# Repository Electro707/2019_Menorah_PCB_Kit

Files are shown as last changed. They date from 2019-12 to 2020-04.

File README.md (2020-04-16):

# 2019_Menorah_PCB_Kit
A soldering kit in the shape of menorah powered by an ATtiny84

This repository is archived, as it's a one-time design.
Now files are hosted on Google Drive.

Link to website, in which the Google Drive link can be found:
[Link](https://electro707.com/documentation/PCB/2019_Menorah/index.php)

I may create a new general reposity for the kit that will be updated as time goes on 
(there also won't be any of the University of New Haven logos on that one).

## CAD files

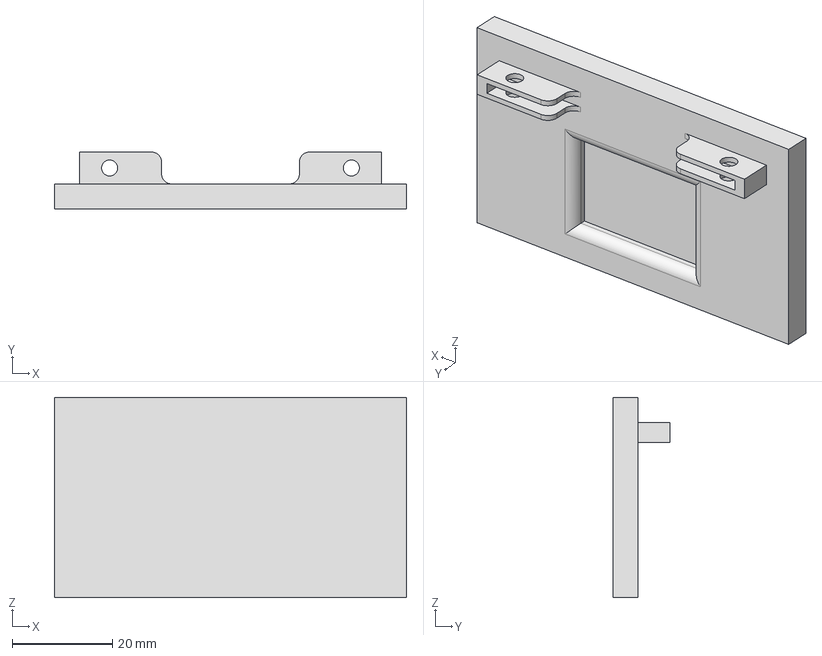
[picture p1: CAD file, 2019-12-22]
Base STEP and STL/Base.stp
70.3 x 11.3 x 40.0 mm

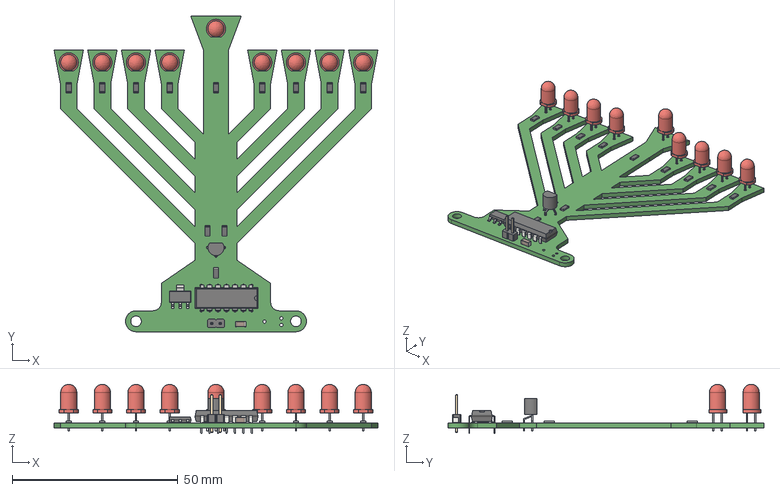
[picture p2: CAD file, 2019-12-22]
CAD-Inventor/Hanukkah.step
97.8 x 95.2 x 14.9 mm

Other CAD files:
CAD-Inventor/Drawing.dwg
Base STEP and STL/Base.stl
CAD-Inventor/9V Battery.ipt
CAD-Inventor/Assembly - Whole.iam
CAD-Inventor/Exploded Views.ipn
CAD-Inventor/Holder.ipt

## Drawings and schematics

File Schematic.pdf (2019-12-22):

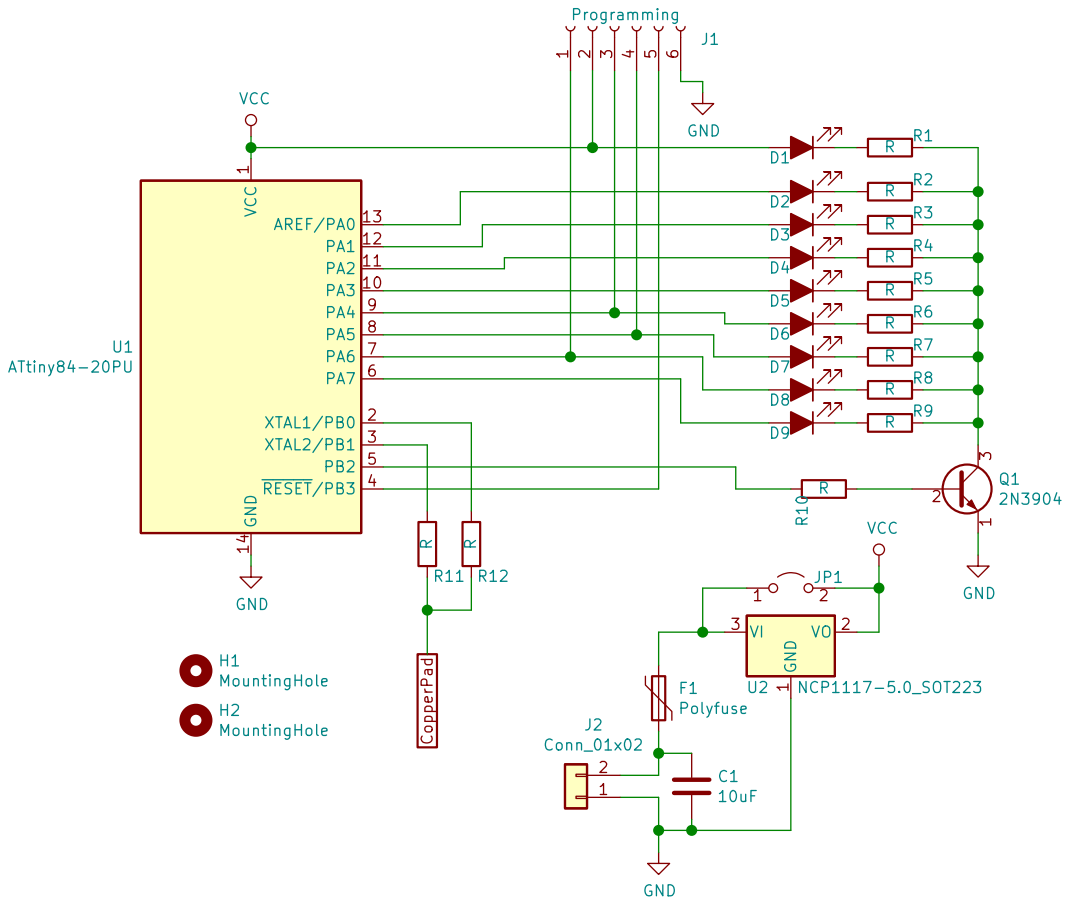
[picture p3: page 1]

1 PA3 10 PA2 11 PA1 12 AREF/PA0 13 GND 14 XTAL1/PB0 2 XTAL2/PB1 3 RESET/PB3 4 PB2 5 PA7 6 PA6 7 PA5 8 PA4 9 U1 ATtiny84-20PU CopperPad R12 R

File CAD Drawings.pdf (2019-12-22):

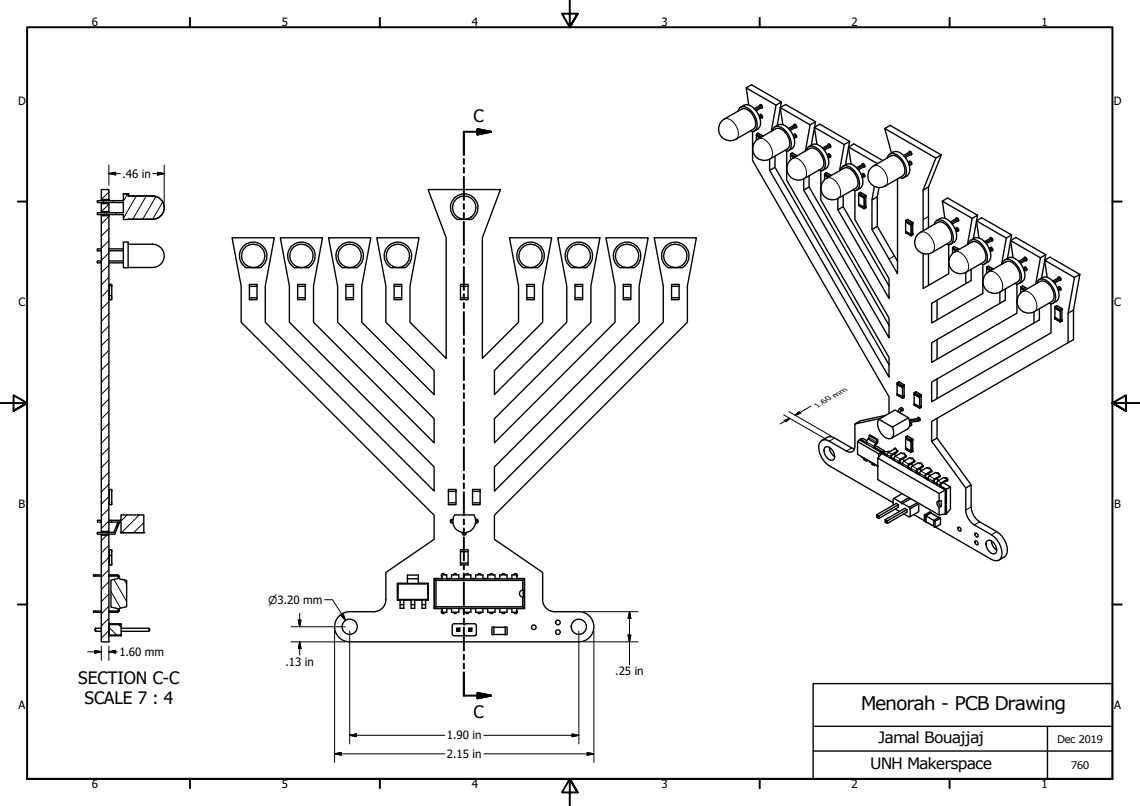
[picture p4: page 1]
SECTION C-C SCALE 7 : 4

Menorah - PCB Drawing

Jamal Bouajjaj | Dec 2019
UNH Makerspace | 760

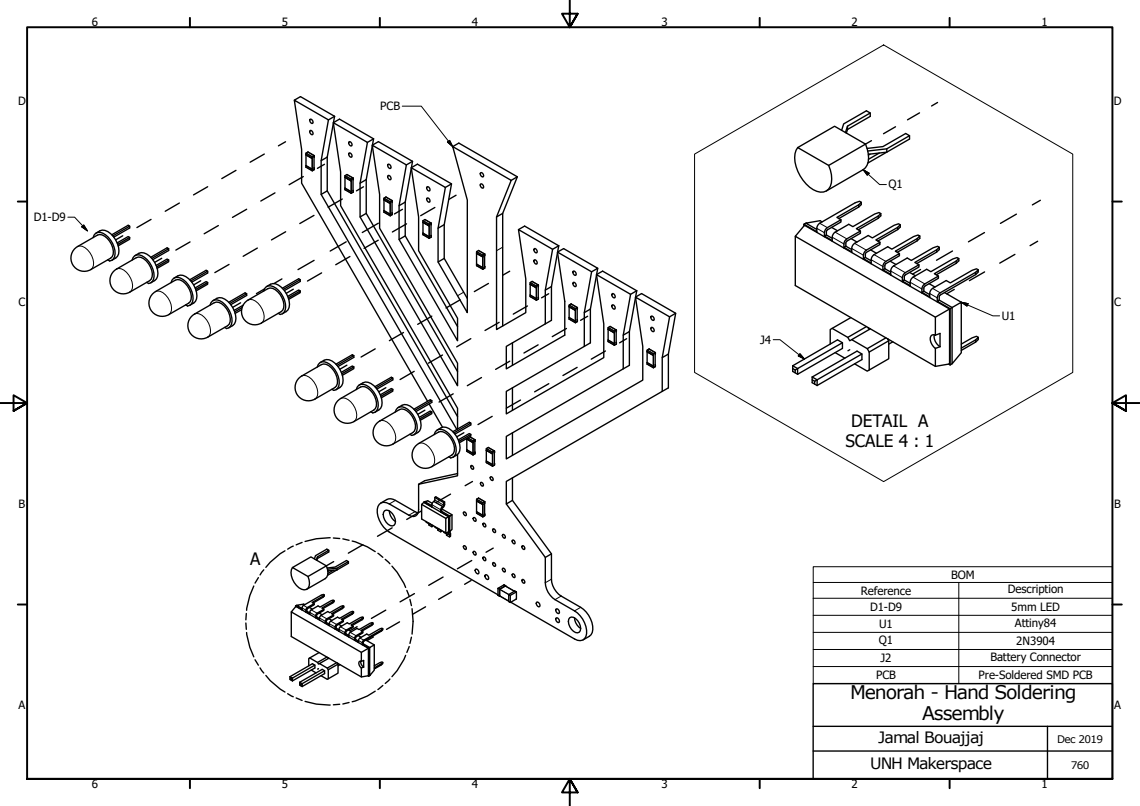
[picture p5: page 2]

R e fe r e n c e | D e s c r i p t i o n
D 1 -D 9 | 5 m m L E D
U 1 | At t i n y 8 4
Q 1 | 2 N 3 9 0 4
J 2 | B a t t e r y C o n n e c t o r
P C B | P r e -S old e r e d S M D P C B

J a m al B o u aj j aj | D e c
U N H M a k e r s p a c e

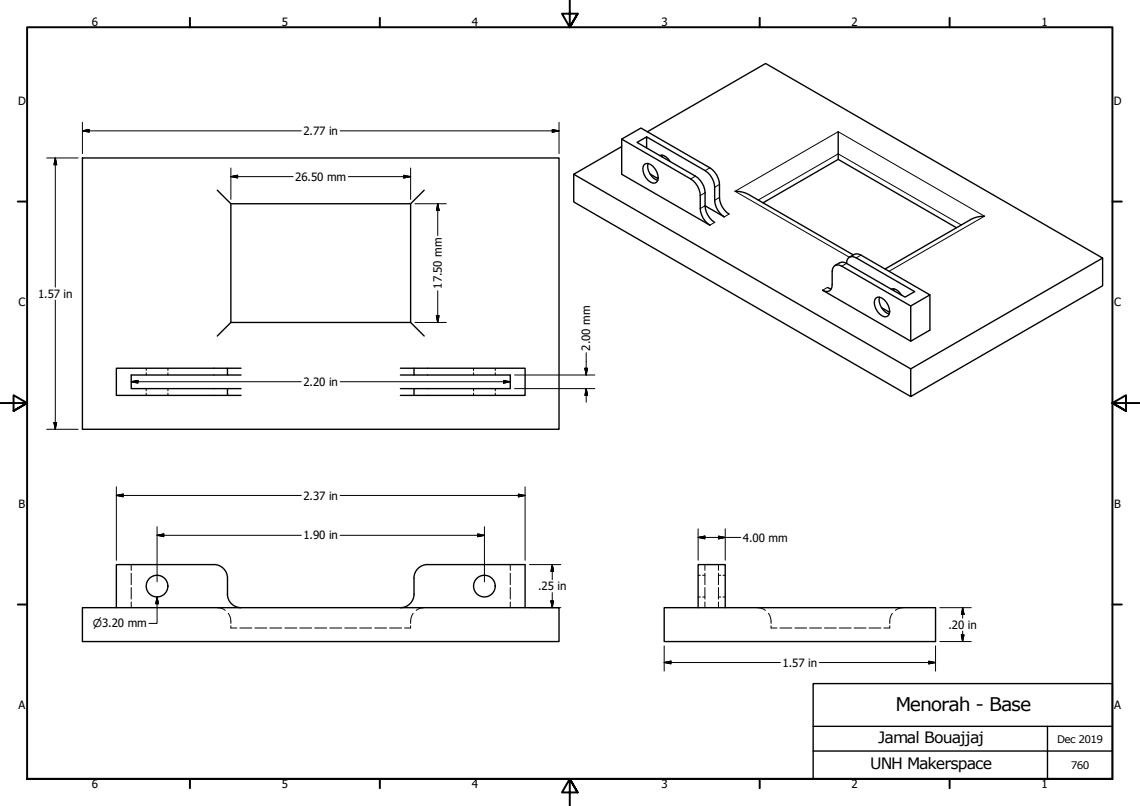
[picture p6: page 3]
Menorah - Base; Jamal Bouajjaj; Dec 2019

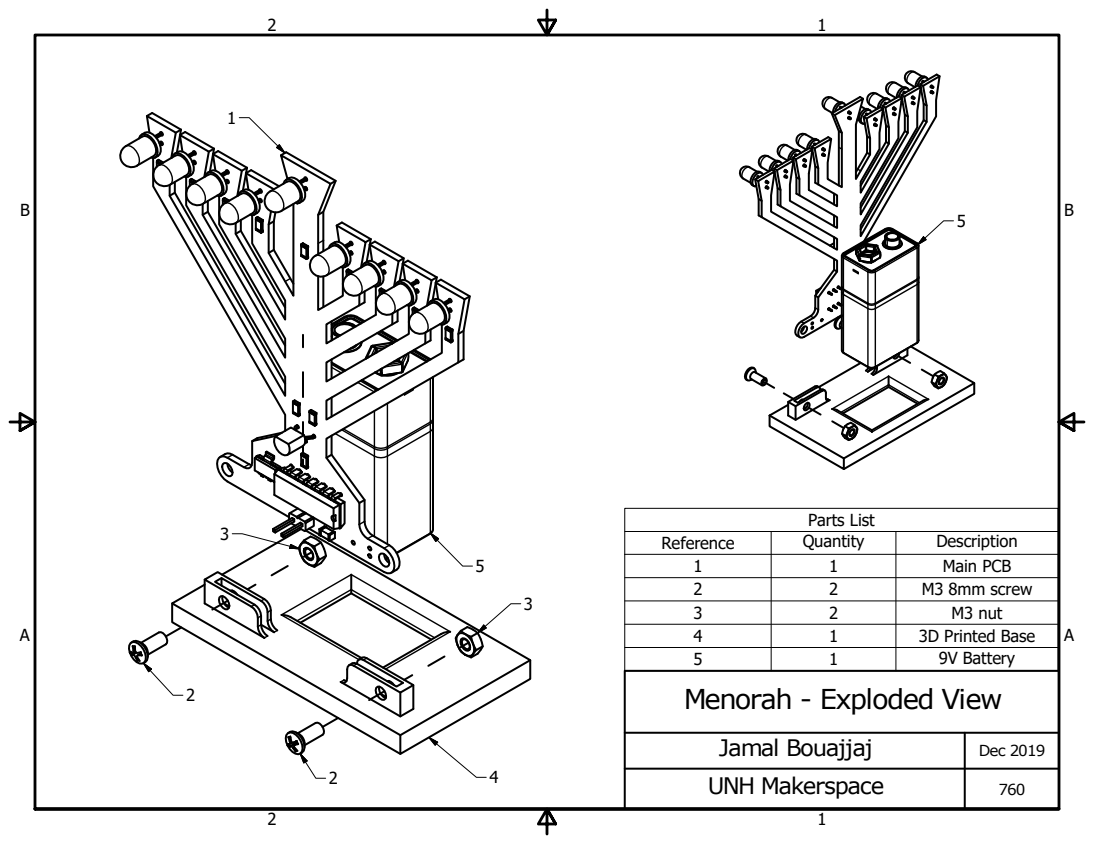
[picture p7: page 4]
Jamal Bouajjaj; Dec 2019; Parts List

Reference | Quantity | Description
1 | 1 | Main PCB
2 | 2 | M3 8mm screw
3 | 2 | M3 nut
4 | 1 | 3D Printed Base
5 | 1 | 9V Battery

Menorah - Exploded View

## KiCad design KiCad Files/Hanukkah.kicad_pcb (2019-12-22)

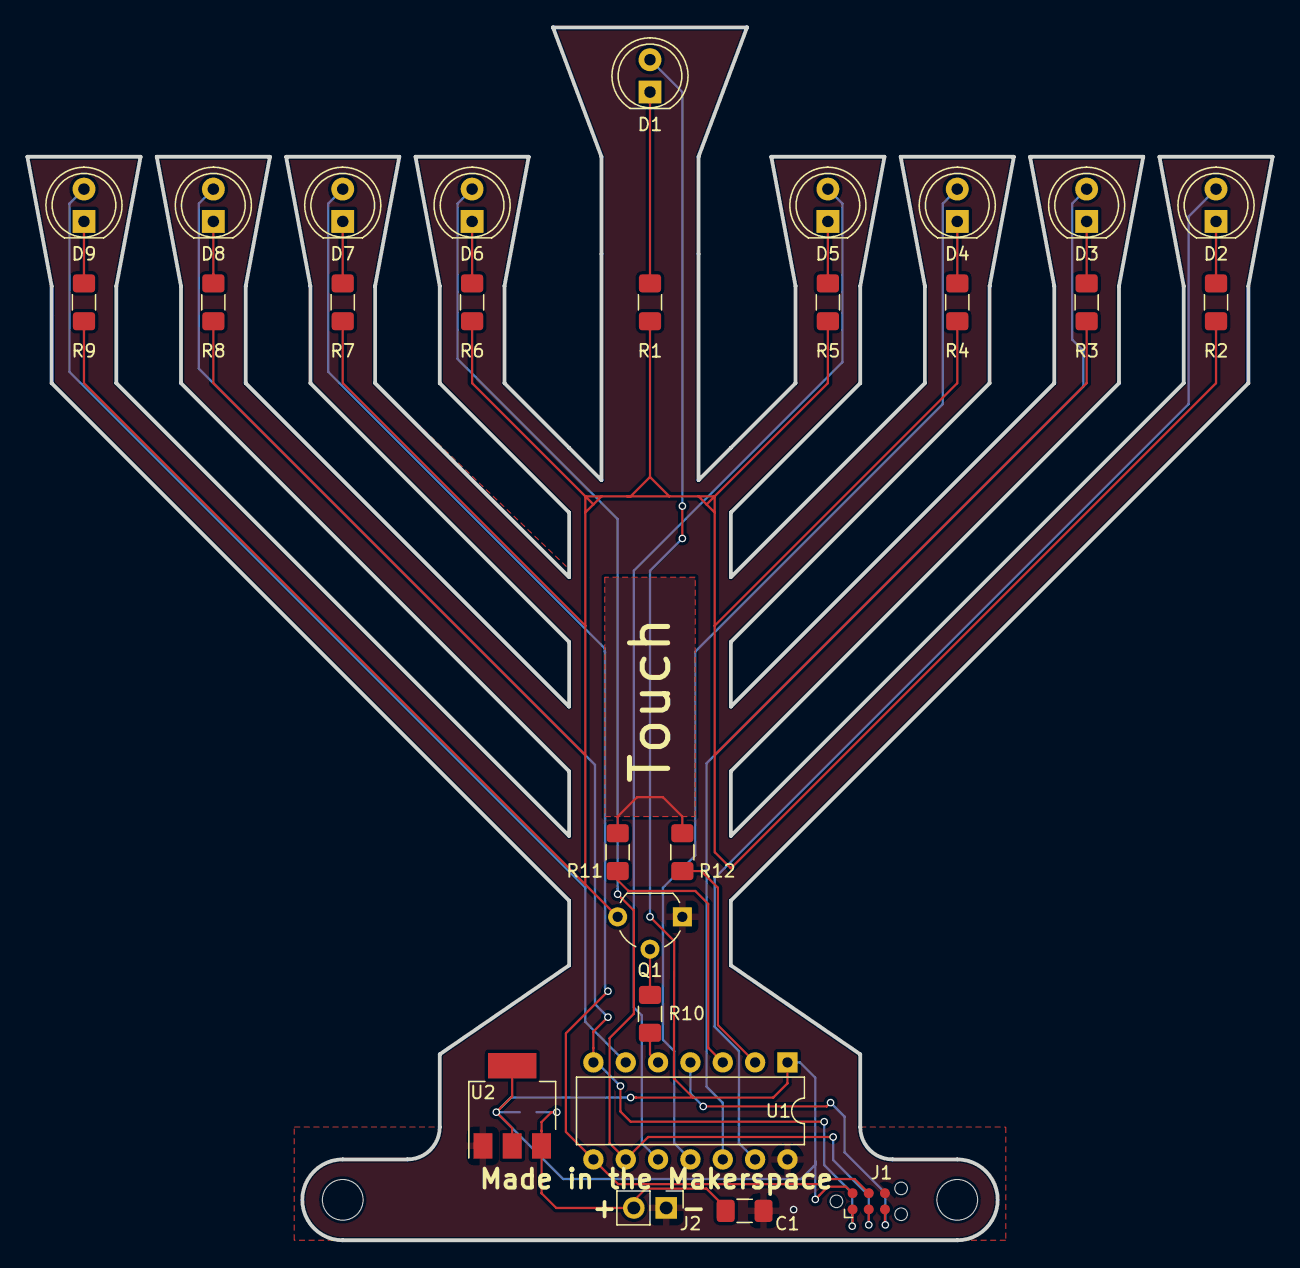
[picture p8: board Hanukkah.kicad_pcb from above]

Board: 2 copper layers, 97.8 x 95.2 mm, 30 parts (1 on the bottom side), 27 nets.

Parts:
C1: 10uF; C_1206_3216Metric_Pad1.42x1.75mm_HandSolder
D1, D2, D3, D4, D5, D6, D7, D8, D9: LED_ALT; LED_D5.0mm
H1, H2: MountingHole; MountingHole_3.2mm_M3_DIN965
J1: Programming; Tag-Connect_TC2030-IDC-NL_2x03_P1.27mm_Vertical
J2: Conn_01x02; PinHeader_1x02_P2.54mm_Vertical
JP1: Jumper_2_Open; SolderJumper-2_P1.3mm_Open_RoundedPad1.0x1.5mm
Q1: 2N3904; TO-92_Wide
R1, R2, R3, R4, R5, R6, R7, R8, R9, R10, R11, R12: R; R_1206_3216Metric_Pad1.42x1.75mm_HandSolder
U1: ATtiny84-20PU; DIP-14_W7.62mm
U2: NCP1117-5.0_SOT223; SOT-223-3_TabPin2

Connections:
CopperPad: R11.1, R12.1
GND: C1.2, J1.6, J2.1, Q1.1, U1.14, U2.1
unnamed: C1.1, J2.2, JP1.1, U2.3
unnamed: D1.1, R1.1
unnamed: D2.1, R2.1
unnamed: D2.2, U1.13
unnamed: D3.1, R3.1
unnamed: D3.2, U1.12
unnamed: D4.1, R4.1
unnamed: D4.2, U1.11
unnamed: D5.1, R5.1
unnamed: D5.2, U1.10
unnamed: D6.1, R6.1
unnamed: D6.2, J1.3, U1.9
unnamed: D7.1, R7.1
unnamed: D7.2, J1.4, U1.8
unnamed: D8.1, R8.1
unnamed: D8.2, J1.1, U1.7
unnamed: D9.1, R9.1
unnamed: D9.2, U1.6
unnamed: J1.5, U1.4
unnamed: Q1.2, R10.2
unnamed: Q1.3, R1.2, R2.2, R3.2, R4.2, R5.2, R6.2, R7.2, R8.2, R9.2
unnamed: R10.1, U1.5
unnamed: R11.2, U1.3
unnamed: R12.2, U1.2
VCC: D1.2, J1.2, JP1.2, U1.1, U2.2

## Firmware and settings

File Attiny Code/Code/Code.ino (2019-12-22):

/************************************************************************************************************************
 *  Touch Menorah Attiny84 Code
 *  By Jamal Bouajjaj
 *
 *  This program controls the LEDs on the 2019 UNH Makerspace Menorah soldering kit. There is a capacitive touch
 *       sensor on the board that you are able to touch to increment the LEDs that are on. All the LEDs are all driven
 *       to GND by a 2N3904 controlled by this controller for PWM control
************************************************************************************************************************/
#include <CapacitiveSensor.h>     // Import the library

#define TRANSISTOR_PIN 8          // Define the pin in which the transistor for the LEDs.
#define CAPSENSE_SEND 9           // Define the capacitive touch send pin
#define CAPSENSE_REC  10          // Define the capacitive touch recieve pin
#define TOUCH_THRESHOLD 110       // Set the threshold value for the captouch

int LEDs_on = 0;                  // Store the number of LEDs that are on
bool last_state = false;          // Store the last capacitive touch state ( pressed or not pressed)
int pwm_millis = 0;

CapacitiveSensor   cs = CapacitiveSensor(CAPSENSE_SEND, CAPSENSE_REC);   // Create the CapacitiveSensor class

void setup()                    
{
   //cs.set_CS_AutocaL_Millis(0xFFFFFFFF);     // Turn off autocalibrate on the capacitive touch channel
   pinMode(TRANSISTOR_PIN, OUTPUT);          // Set the Transistor pin as an output
   // Set the entirety of PORT A as output (All LEDs are connected to this port)
   DDRA = 0xFF;
   
   // The following code is to save power on unused preiferals
   ACSR |= (1<<ACD);              // Turn off Analog Comparator
   ADCSRA &= (1<<ADEN);           // Turn off ADC
   PRR |= (1<<PRADC);             // Shut down ADC
   
    //digitalWrite(TRANSISTOR_PIN, HIGH);.
    pwm_millis = millis();
}

void loop()                    
{
    long cs_val =  cs.capacitiveSensor(30);     // Detect the arbritrary capacitance on the copper pad

    // If above threshold and previous state is off, increment the operating mode
    if(cs_val > TOUCH_THRESHOLD){
      if(last_state == false){    // If pressed and the previous state is off, change the mode
        last_state = true;
        LEDs_on++;
        if(LEDs_on > 8){
          LEDs_on = 0;
        }
        turnOnLEDs(LEDs_on);
        delay(100);
      }
    }
    else{   // If the previous press state is on and the pad isn't pressed, revert the previous pressed state to false
      if(last_state == true){
        last_state = false;
        delay(50);
      }
    }

    if(millis() - pwm_millis > 50){
      uint8_t rand_pwm = random(100,180);
      analogWrite(TRANSISTOR_PIN, rand_pwm);
      pwm_millis = millis();
    }
}

// Function to turn on a certain number of LEDs from left to right
void turnOnLEDs(int numb_leds){
  if(numb_leds > 8){numb_leds = 8;}
  PORTA = ((1<<(8-numb_leds)) - 1);
}
